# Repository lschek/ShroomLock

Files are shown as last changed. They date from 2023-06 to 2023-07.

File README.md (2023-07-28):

# ShroomLock -  an Interlocking Metasurface Mechanism

<p align="center">
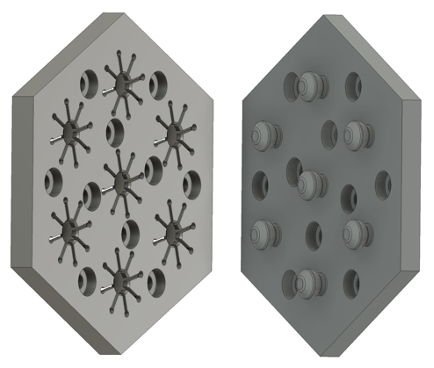
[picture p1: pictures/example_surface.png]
Example of hexagonal surface with locking mechanisms.
  
  GIF of the snapping
</p>

## Introduction
Welcome to the ShroomLock repository! Here, you will find the design files and resources for the interlocking metasurface mechanism known as ShroomLock. SHroomLock is a snapping mechanism which means that it exhibits significant deformation during assembly and disassembly, while experiencing only minor deformation when locked together. Think of it like Lego but different.

## Overview
ShroomLock is composed of two key elements: a pin element and a spring element that are distributed over a surface. The mechanism is highly scalable, making it adaptable to a wide range of surface shapes, while ensuring reliable snapping behavior. One of its unique features is that the entire surface mechanism can be traced back to a single snapping element, which greatly simplifies testing.

## Printing
Here you can find the printing parameters used to print the parts on an Anycubic Vyper 3D printer. We used FLEX HARD 1.75 mm TPU filament from extrudr.

<p align="center">
  <table>
    <tr>
      <th>Parameter</th>
      <th>Value/Setting</th>
    </tr>
    <tr>
      <td>Layer Height</td>
      <td>0.1 mm</td>
    </tr>
    <tr>
      <td>Build Plate Temperature</td>
      <td>55 °C</td>
    </tr>
    <tr>
      <td>Line Width</td>
      <td>0.4 mm</td>
    </tr>
    <tr>
      <td>Flow</td>
      <td>103 %</td>
    </tr>
    <tr>
      <td>Wall Thickness</td>
      <td>2.4 mm</td>
    </tr>
    <tr>
      <td>Print Speed</td>
      <td>25.0 mm/s</td>
    </tr>
    <tr>
      <td>Z Seam Alignment</td>
      <td>Random</td>
    </tr>
    <tr>
      <td>Initial Layer Speed</td>
      <td>15.0 mm/s</td>
    </tr>
    <tr>
      <td>Top/Bottom Thickness</td>
      <td>1.5 mm</td>
    </tr>
    <tr>
      <td>Enable Retraction</td>
      <td>☑</td>
    </tr>
    <tr>
      <td>Infill Density</td>
      <td>20.0 %</td>
    </tr>
    <tr>
      <td>Combing Mode</td>
      <td>All</td>
    </tr>
    <tr>
      <td>Infill Pattern</td>
      <td>Gyroid</td>
    </tr>
    <tr>
      <td>Enable Print Cooling</td>
      <td>☑</td>
    </tr>
    <tr>
      <td>Printing Temperature</td>
      <td>215 °C</td>
    </tr>
    <tr>
      <td>Fan Speed</td>
      <td>100 %</td>
    </tr>
    <tr>
      <td>Temperature Initial Layer</td>
      <td>225 °C</td>
    </tr>
    <tr>
      <td>Print Sequence</td>
      <td>One at a Time</td>
    </tr>
  </table>
</p>

## Experimental Results
<p align="center">
  Measured displacement-force plots for the mechanism.
</p>

We have experimentally examined the force-displacement characteristics of ShroomLock by conducting tests on the unsnapping behavior when pulling a single pin element out of a spring element. The results are shown above, and you can find all the measured data in this repository.

## Numerical Modeling
<p align="center">
  Numerical results for the mechanism.
</p>

Using [FEniCSx](https://fenicsproject.org/), we performed numerical modeling to further investigate the behavior of ShroomLock. For a detailed explanation of the contact model employed here, refer to [(Bleyer, 2018)](https://comet-fenics.readthedocs.io/en/latest/demo/contact/penalty.html). The repository contains all the necessary code and meshes for the numerical simulations.

## Repository Contents
This repository consists of five folders:
* [data](./data/) which contains all measured data from experimental testing,
* [design](./design/) which contains the printing files in STEP format
* [numerics](./numerics/) which contains meshes and code for the numerical modeling
* [pictures](./pictures/) which contains example pictures for this readme
* [testing](./testing/) which contains the code for evaluating the experimental measurements

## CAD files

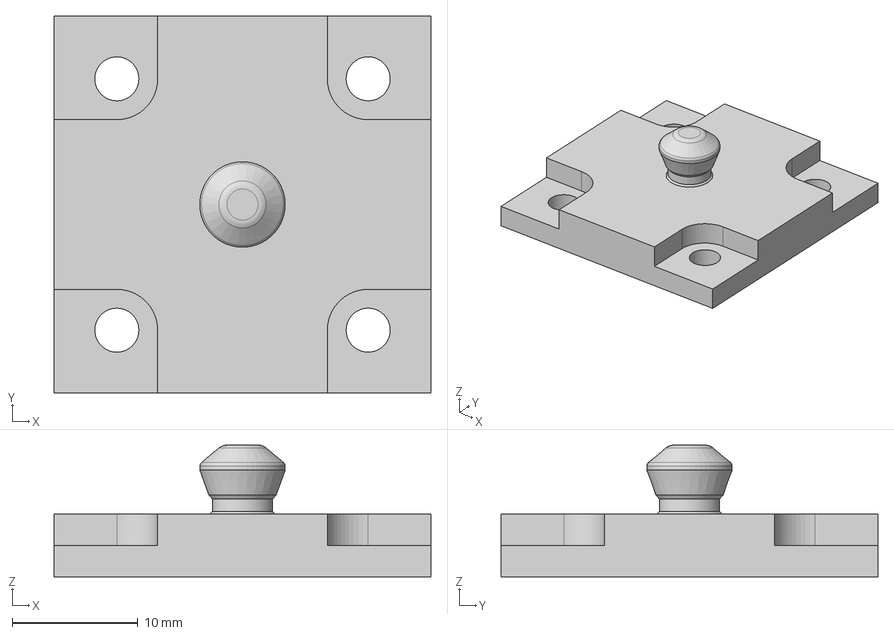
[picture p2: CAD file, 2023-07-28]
design/ShroomLock-V7-Shroom.step
30.0 x 30.0 x 10.5 mm

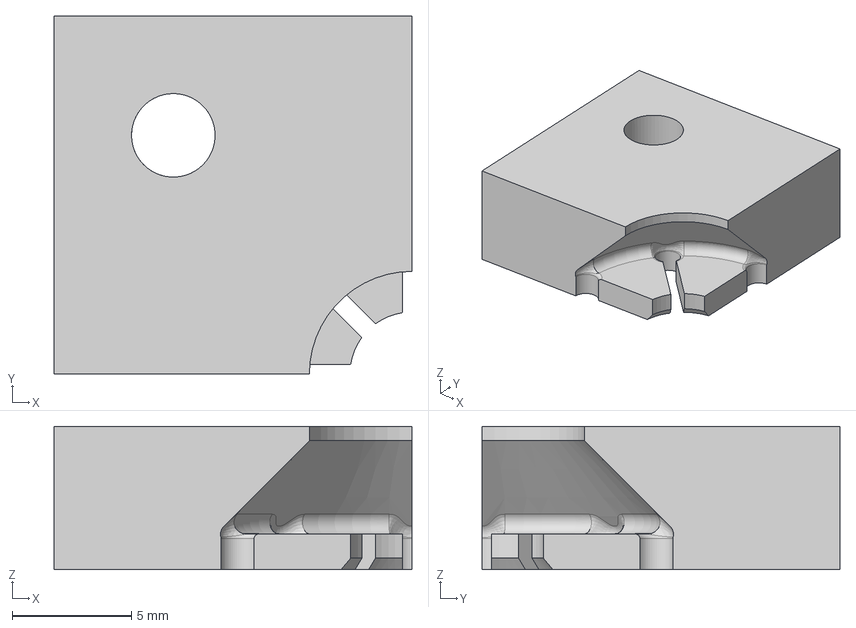
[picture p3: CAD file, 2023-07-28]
numerics/meshes/ShroomLock-V7-Lock-quarter.step
15.0 x 15.0 x 6.00 mm

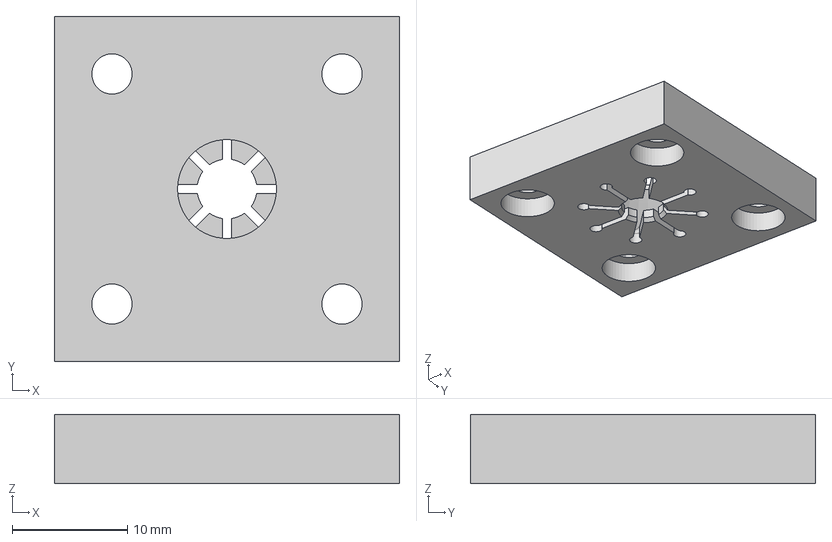
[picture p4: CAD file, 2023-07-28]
design/ShroomLock-V7-Lock.step
30.0 x 30.0 x 6.00 mm

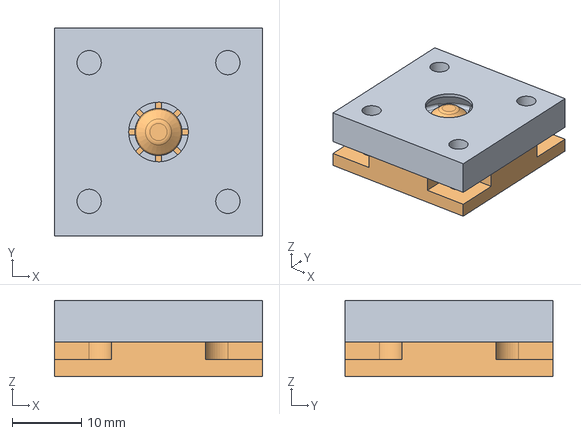
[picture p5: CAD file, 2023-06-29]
design/ShroomLock-V7-Print.step
30.0 x 30.0 x 11.0 mm

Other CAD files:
numerics/meshes/ShroomLock-V7-Lock.step

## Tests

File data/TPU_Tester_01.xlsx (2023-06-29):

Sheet: Parameter
Überschrift | Prüfprotokoll
Art und Bezeichnung
Werkstoff | PLA grau Prusa
Probentyp | Flachprobe
Maschinendaten

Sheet: Ergebnisse Probe 6
Proben-Nr. | Probenbezeichnung | Lc | h0 | Probenkennung | FBruch | dL(Bruch) | W(Bruch) | S0 | a0 | b0 | Kommentar | Datum/Uhrzeit | FotoJe1 | FotoMehrerWerte1 | ZeitBeiFoto1 | Fmax | dL(Fmax) | W(Fmax) | Fmin | dL(Fmin) | tPrüfung | L0 | Lc
 |  | mm | mm |  | N | mm | Nmm | mm² | mm | mm |  |  | mm |  | s | N | mm | Nmm | N | mm | s | mm | mm
1 | Probe 6 | 119 | 28.18918959 | PLA_UC_6 | 0.6330842376 | 5.791211128 | 26.70918092 | 30 | 2 | 15 | TPU_Tester01 | 45085.44745 | 1:0,00 |  | 1:0,00 | 6.601232529 | 4.607923031 | 21.36854758 | 0.4683555365 | 2.772955304e-05 | 174.22 | 119.1872108 | 119.1872108
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

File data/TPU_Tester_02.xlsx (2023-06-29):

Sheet: Parameter
Überschrift | Prüfprotokoll
Art und Bezeichnung
Werkstoff | PLA grau Prusa
Probentyp | Flachprobe
Maschinendaten

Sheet: Ergebnisse Probe 2
Proben-Nr. | Probenbezeichnung | Lc | h0 | Probenkennung | FBruch | dL(Bruch) | W(Bruch) | S0 | a0 | b0 | Kommentar | Datum/Uhrzeit | FotoJe1 | FotoMehrerWerte1 | ZeitBeiFoto1 | Fmax | dL(Fmax) | W(Fmax) | Fmin | dL(Fmin) | tPrüfung | L0 | Lc
 |  | mm | mm |  | N | mm | Nmm | mm² | mm | mm |  |  | mm |  | s | N | mm | Nmm | N | mm | s | mm | mm
2 | Probe 2 | 1 | 28.14504414 | TPU_Tester 02 |  |  |  | 150 | 5 | 30 | TPU_Tester 02 | 45085.45461 | 1:0,00; 2:1,14; 3:2,29; 4:3,43; 5:4,57; 6:5,72; 7:6,86; 8:8,00 |  | 1:0,00; 2:34,78; 3:69,07; 4:103,36; 5:137,66; 6:171,94; 7:206,24; 8:240,55 | 6.757718086 | 4.020729065 | 17.49001584 | 0.1655000895 | 5.862201691 | 359.02 | 1.14311222 | 1.14311222
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

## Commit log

2023-06-29 First commit to repository
    This is my suggestion to the structure of our repository.
    Note, that the numerics are still a mess and nothing is final!
    [Full-Lamelle.step, Full_LamelleV2.step, Full_LamelleV7.step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]
2023-07-28 Clean up and code fixes
    [Full-Lamelle.step, Full_LamelleV2.step, Full_LamelleV7.step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]
